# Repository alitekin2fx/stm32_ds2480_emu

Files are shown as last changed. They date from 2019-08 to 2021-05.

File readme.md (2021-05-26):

# STM32 DS2480 emulation project.
DS2480 is a 1-Wire line driver IC that works with OneWireLinkLayer library and several evaluation kit softwares from Maxim. In this project i have demostrated how to emulate DS2480 chip on STM32. You can use this usb stick to access your 1-Wire IC's with above softwares or with your own software using the OneWireLinkLayer library.

# How to upload firmware
1) Download and install the DfuSe application from ST.
2) Solder "DFU" jumper and plug it into USB port.
3) Install driver if needed.
4) Run DfuSe and press "choose" button under "Update and verify action" section.
5) Locate to *.dfu file (software/stm32_ds2480_emu.dfu)
5) Press "Upgrade" button
6) Press "Leave DFU mode" button.
8) Remove solder from "DFU" jumper

# Licenses
- Software license: MIT
- Hardware license: CERN v1.2

OSHW-TR000001 (https://certification.oshwa.org/tr000001.html)

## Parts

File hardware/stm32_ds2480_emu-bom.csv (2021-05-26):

Quantity | References | Value | Footprint | Brand | Part Number | LCSC Part #
2 | C1, C2 | 100nF | Capacitor_SMD:C_0603_1608Metric | SAMSUNG | CL10B104KB8NNNC
1 | C3 | 2.2uF | Capacitor_SMD:C_0603_1608Metric | SAMSUNG | CL10A225KO8NNNC
1 | C4 | 1uF | Capacitor_SMD:C_0603_1608Metric | SAMSUNG | CL10A105KO8NNNC
1 | D1 | LED1 | LED_SMD:LED_0603_1608Metric | LITEON | LTST-C190KGKT
1 | D2 | LED2 | LED_SMD:LED_0603_1608Metric | LITEON | LTST-C191KRKT
1 | D3 | 5.1V | Diode_SMD:D_SOT-23_ANK | HOTTECH | BZX84C5V1-HT
1 | F1 | Polyfuse | Fuse:Fuse_0805_2012Metric | BOURNS | MF-PSMF010X-2
1 | J2 | USB_A | Connector_USB:USB_A_CNCTech_1001-011-01101_Horizontal | CONNFLY | DS1098-WN0
1 | Q1 | SI2302CDS | Package_TO_SOT_SMD:SOT-23 | Vishay | SI2302CDS-T1-GE3
2 | R1, R2 | 100R | Resistor_SMD:R_0603_1608Metric | ROYALOHM | 0603SAJ0101T5E
1 | R3 | 2.2K | Resistor_SMD:R_0805_2012Metric | ROYALOHM | 0805S8J0222T5E
2 | R4, R7 | 4.7R | Resistor_SMD:R_0805_2012Metric | ROYALOHM | 0805S8J047JT5E
2 | R5, R6 | 10K | Resistor_SMD:R_0603_1608Metric | ROYALOHM | 0603SAJ0103T5E
1 | U1 | USBLC6-2SC6 | Package_TO_SOT_SMD:SOT-23-6 | STM | USBLC6-2SC6
1 | U2 | STM32F042F6Px | Package_SO:TSSOP-20_4.4x6.5mm_P0.65mm | STM | STM32F042F6P6
1 | U3 | AP2204K-3.3 | Package_TO_SOT_SMD:SOT-23-5 | DIODES | AP2204K-3.3TRG1

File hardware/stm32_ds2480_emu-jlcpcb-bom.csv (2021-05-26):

Comment | Designator | Footprint | LCSC Part #
100nF | C1,C2 | Capacitor_SMD:C_0603_1608Metric
2.2uF | C3 | Capacitor_SMD:C_0603_1608Metric
1uF | C4 | Capacitor_SMD:C_0603_1608Metric
LED1 | D1 | LED_SMD:LED_0603_1608Metric
LED2 | D2 | LED_SMD:LED_0603_1608Metric
5.1V | D3 | Diode_SMD:D_SOT-23_ANK
Polyfuse | F1 | Fuse:Fuse_0805_2012Metric
Fiducial | FID1,FID2 | Fiducial:Fiducial_0.5mm_Mask1.5mm
OW | J1 | Connector_PinHeader_2.54mm:PinHeader_1x02_P2.54mm_Vertical
USB_A | J2 | Connector_USB:USB_A_CNCTech_1001-011-01101_Horizontal
SWD | J3 | Connector_PinHeader_1.27mm:PinHeader_1x05_P1.27mm_Vertical
PUP | JP1 | Jumper:SolderJumper-2_P1.3mm_Open_RoundedPad1.0x1.5mm
DFU | JP2 | Jumper:SolderJumper-2_P1.3mm_Open_RoundedPad1.0x1.5mm
SI2302CDS | Q1 | Package_TO_SOT_SMD:SOT-23
100R | R1,R2 | Resistor_SMD:R_0603_1608Metric
2.2K | R3 | Resistor_SMD:R_0805_2012Metric
4.7R | R4,R7 | Resistor_SMD:R_0805_2012Metric
10K | R5,R6 | Resistor_SMD:R_0603_1608Metric
SYNC | TP1 | TestPoint:TestPoint_Pad_D1.0mm
NRST | TP2 | TestPoint:TestPoint_Pad_D1.0mm
USBLC6-2SC6 | U1 | Package_TO_SOT_SMD:SOT-23-6
STM32F042F6Px | U2 | Package_SO:TSSOP-20_4.4x6.5mm_P0.65mm
AP2204K-3.3 | U3 | Package_TO_SOT_SMD:SOT-23-5

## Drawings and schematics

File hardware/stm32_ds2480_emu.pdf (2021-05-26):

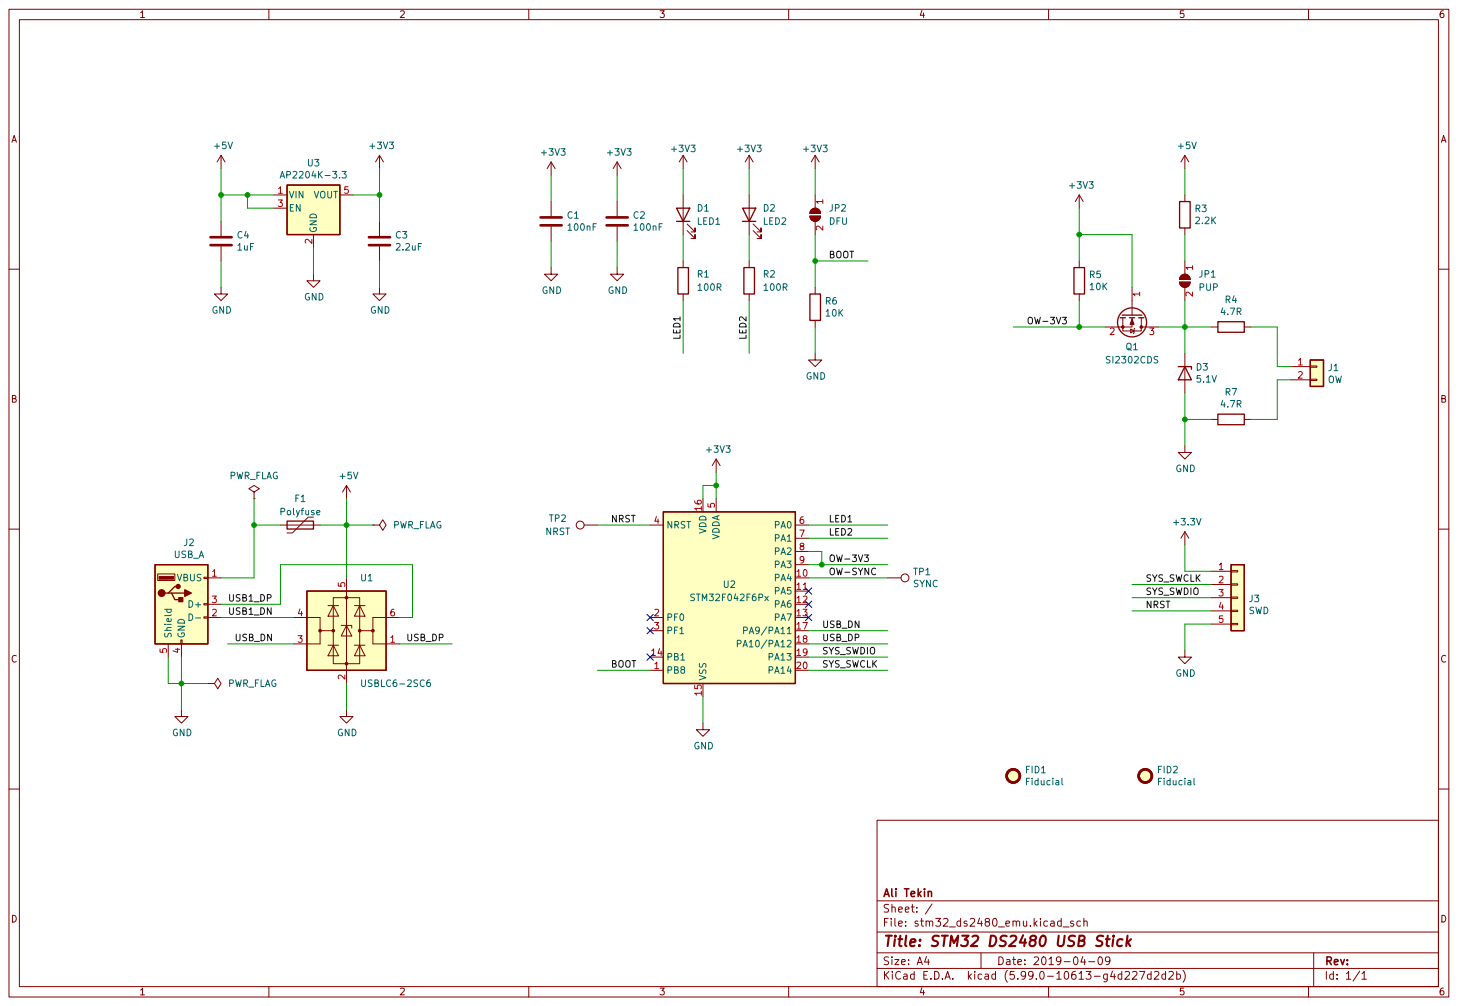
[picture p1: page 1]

File: stm32_ds2480_emu.kicad_sch Sheet: / Ali Tekin

Id: 1/1 Title: STM32 DS2480 USB Stick

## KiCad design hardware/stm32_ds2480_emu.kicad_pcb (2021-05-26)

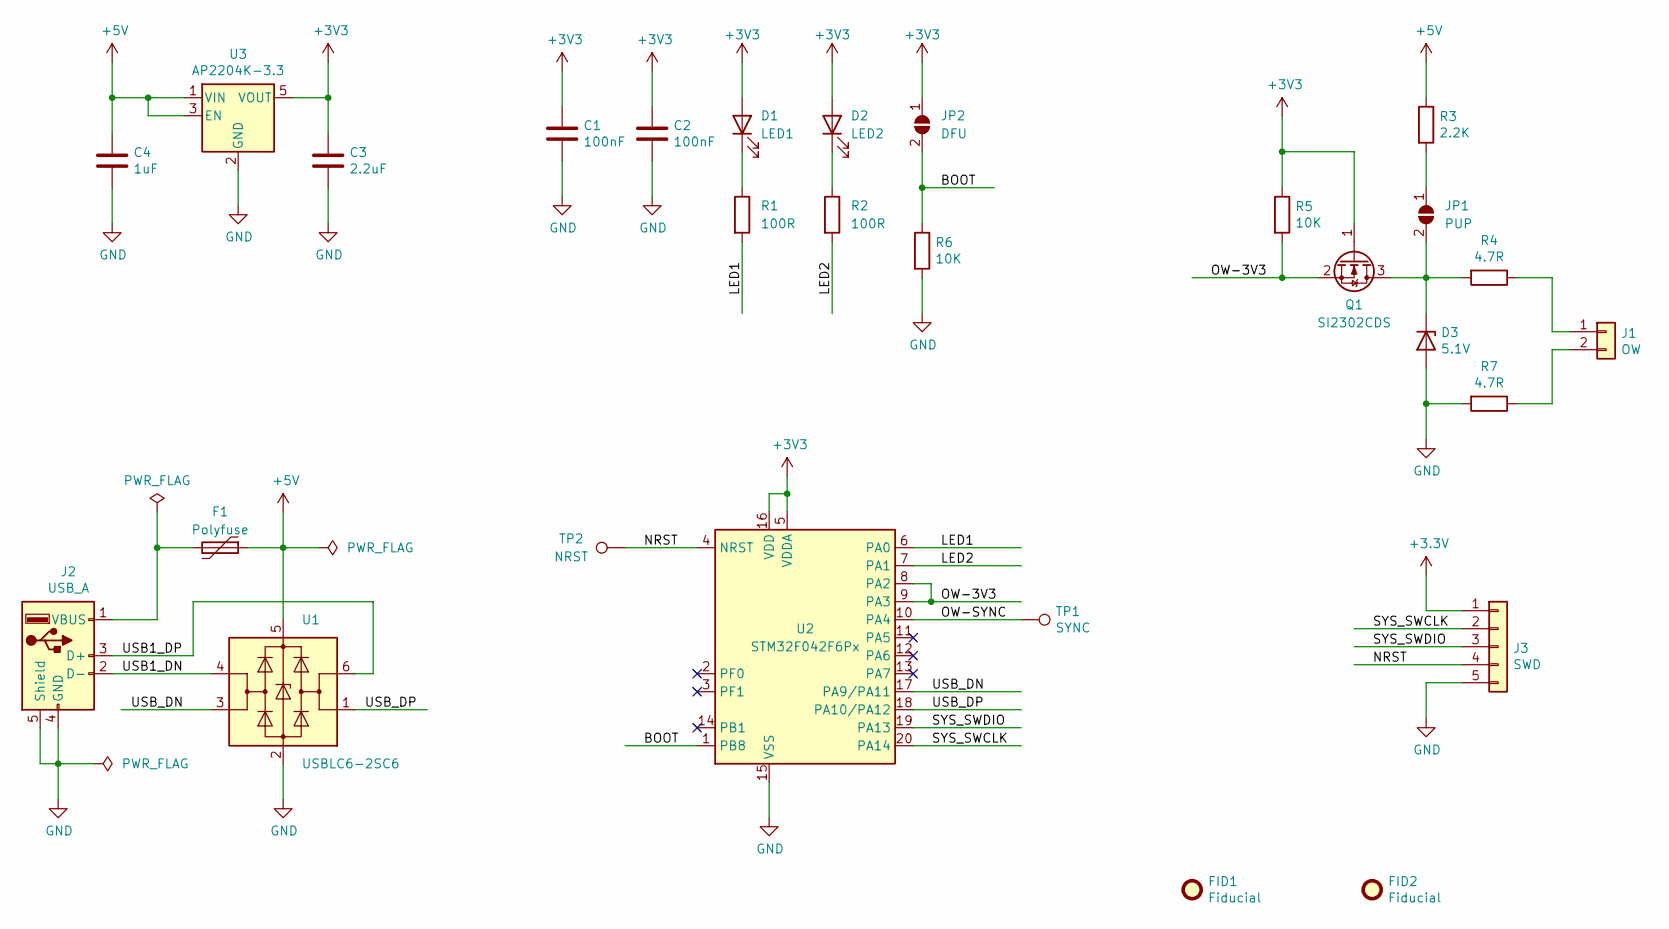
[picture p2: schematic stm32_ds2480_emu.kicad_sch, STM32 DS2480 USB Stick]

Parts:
C1, C2: 100nF; C_0603_1608Metric; Part Number CL10B104KB8NNNC
C3: 2.2uF; C_0603_1608Metric; Part Number CL10A225KO8NNNC
C4: 1uF; C_0603_1608Metric; Part Number CL10A105KO8NNNC
D1: LED1; LED_0603_1608Metric; Part Number LTST-C190KGKT
D2: LED2; LED_0603_1608Metric; Part Number LTST-C191KRKT
D3: 5.1V; D_SOT-23_ANK; Part Number BZX84C5V1-HT
F1: Polyfuse; Fuse_0805_2012Metric; Part Number MF-PSMF010X-2
FID1, FID2: Fiducial; Fiducial_0.5mm_Mask1.5mm
J1: OW; PinHeader_1x02_P2.54mm_Vertical
J2: USB_A; USB_A_CNCTech_1001-011-01101_Horizontal; Part Number DS1098-WN0
J3: SWD; PinHeader_1x05_P1.27mm_Vertical
JP1: PUP; SolderJumper-2_P1.3mm_Open_RoundedPad1.0x1.5mm
JP2: DFU; SolderJumper-2_P1.3mm_Open_RoundedPad1.0x1.5mm
Q1: SI2302CDS; SOT-23; Part Number SI2302CDS-T1-GE3
R1, R2: 100R; R_0603_1608Metric; Part Number 0603SAJ0101T5E
R3: 2.2K; R_0805_2012Metric; Part Number 0805S8J0222T5E
R4, R7: 4.7R; R_0805_2012Metric; Part Number 0805S8J047JT5E
R5, R6: 10K; R_0603_1608Metric; Part Number 0603SAJ0103T5E
TP1: SYNC; TestPoint_Pad_D1.0mm
TP2: NRST; TestPoint_Pad_D1.0mm
U1: USBLC6-2SC6; SOT-23-6; Part Number USBLC6-2SC6
U2: STM32F042F6Px; TSSOP-20_4.4x6.5mm_P0.65mm; Part Number STM32F042F6P6
U3: AP2204K-3.3; SOT-23-5; Part Number AP2204K-3.3TRG1

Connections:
+5V: C4.1, F1.1, R3.1, U1.5 (VBUS), U3.1 (VIN), U3.3 (EN)
/BOOT: JP2.2 (B), R6.1, U2.1 (PB8)
/LED1: R1.2, U2.6 (PA0)
/LED2: R2.2, U2.7 (PA1)
/NRST: J3.4, TP2.1, U2.4 (NRST)
/OW-3V3: Q1.2 (S), R5.2, U2.8 (PA2), U2.9 (PA3)
/OW-SYNC: TP1.1, U2.10 (PA4)
/SYS_SWCLK: J3.2, U2.20 (PA14)
/SYS_SWDIO: J3.3, U2.19 (PA13)
/USB1_DN: J2.2 (D-), U1.4 (I/O2)
/USB1_DP: J2.3 (D+), U1.6 (I/O1)
/USB_DN: U1.3 (I/O2), U2.17 (PA9/PA11)
/USB_DP: U1.1 (I/O1), U2.18 (PA10/PA12)
GND: C1.2, C2.2, C3.2, C4.2, D3.2 (A), J2.4 (GND), J2.5 (Shield), J3.5, R6.2, R7.2, U1.2 (GND), U2.15 (VSS), U3.2 (GND)
unnamed: D1.1 (K), R1.1
unnamed: D2.1 (K), R2.1
unnamed: D3.1 (K), JP1.2 (B), Q1.3 (D), R4.2
unnamed: F1.2, J2.1 (VBUS)
unnamed: J1.1, R4.1
unnamed: J1.2, R7.1
unnamed: JP1.1 (A), R3.2

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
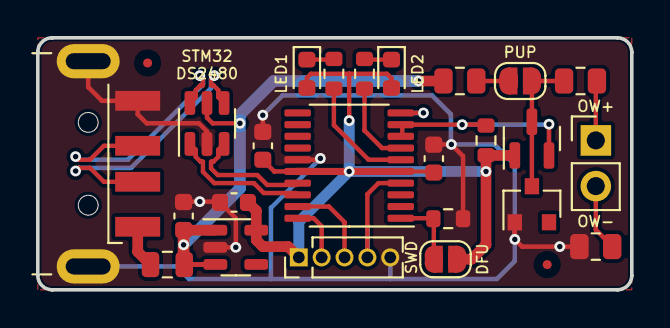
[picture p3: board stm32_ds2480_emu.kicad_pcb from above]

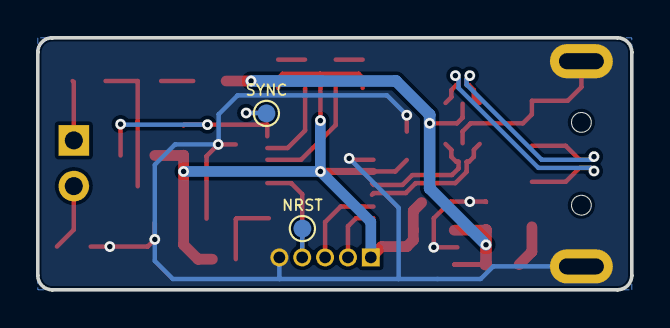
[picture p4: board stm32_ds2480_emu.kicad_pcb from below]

Board: 2 copper layers, 33.0 x 14.0 mm, 28 parts (2 on the bottom side), 22 nets.

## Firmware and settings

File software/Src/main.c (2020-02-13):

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

/* Includes ------------------------------------------------------------------*/
#include "main.h"
#include "usb_device.h"

/* USER CODE BEGIN Includes */
#include "ds2480b.h"
#include "usbd_cdc.h"

/* USER CODE END Includes */

UART_HandleTypeDef huart2;
DMA_HandleTypeDef hdma_usart2_rx;
DMA_HandleTypeDef hdma_usart2_tx;

/* USER CODE BEGIN PV */
struct ds2480b ds2480b;
uint32_t led1_tick_count;
uint32_t led2_tick_count;
__IO int cdc_receiver_busy;
__IO uint32_t cdc_rx_data_length;
__IO const uint8_t *cdc_rx_buffer;
extern USBD_HandleTypeDef hUsbDeviceFS;

/* USER CODE END PV */

void SystemClock_Config(void);
static void MX_GPIO_Init(void);
static void MX_DMA_Init(void);
static void MX_USART2_UART_Init(void);
/* USER CODE BEGIN PFP */

/* USER CODE END PFP */

/**
  * @brief  The application entry point.
  * @retval int
  */
int main(void)
{
  

  /* MCU Configuration--------------------------------------------------------*/

  /* Reset of all peripherals, Initializes the Flash interface and the Systick. */
  HAL_Init();

  /* USER CODE BEGIN Init */
  cdc_receiver_busy = 0;
  cdc_rx_data_length = 0;
  ds2480b_reset(&ds2480b);

  /* USER CODE END Init */

  /* Configure the system clock */
  SystemClock_Config();

  /* Initialize all configured peripherals */
  MX_GPIO_Init();
  MX_DMA_Init();
  MX_USART2_UART_Init();
  MX_USB_DEVICE_Init();
  /* Infinite loop */
  /* USER CODE BEGIN WHILE */
  while (1)
  {
	  if (!cdc_receiver_busy)
	  {
		  if (cdc_rx_data_length != 0)
		  {
			  ds2480b_handle_data(&ds2480b, (const uint8_t*)cdc_rx_buffer, cdc_rx_data_length);
			  cdc_rx_data_length = 0;
		  }

		  if (hUsbDeviceFS.pClassData != 0)
		  {
			  cdc_receiver_busy = 1;
			  USBD_CDC_ReceivePacket(&hUsbDeviceFS);
		  }
	  }

	  if (HAL_GPIO_ReadPin(LED1_GPIO_Port, LED1_Pin) == GPIO_PIN_RESET)
	  {
		  if (HAL_GetTick() - led1_tick_count > 100)
			  HAL_GPIO_WritePin(LED1_GPIO_Port, LED1_Pin, GPIO_PIN_SET);
	  }

	  if (HAL_GPIO_ReadPin(LED2_GPIO_Port, LED2_Pin) == GPIO_PIN_RESET)
	  {
		  if (HAL_GetTick() - led2_tick_count > 100)
			  HAL_GPIO_WritePin(LED2_GPIO_Port, LED2_Pin, GPIO_PIN_SET);
	  }
    /* USER CODE END WHILE */

    /* USER CODE BEGIN 3 */

  }
  /* USER CODE END 3 */
}

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
/* USER CODE BEGIN 4 */
void cdc_break_callback()
{
	ds2480b_reset(&ds2480b);
}

void cdc_data_received_callback(const uint8_t *data, uint32_t data_length)
{
	cdc_rx_buffer = data;
	cdc_rx_data_length = data_length;
	cdc_receiver_busy = 0;
}

/* USER CODE END 4 */
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


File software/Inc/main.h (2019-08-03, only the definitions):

#define LED1_Pin GPIO_PIN_0
#define LED1_GPIO_Port GPIOA
#define LED2_Pin GPIO_PIN_1
#define LED2_GPIO_Port GPIOA
#define OW_TX_Pin GPIO_PIN_2
#define OW_TX_GPIO_Port GPIOA
#define OW_RX_Pin GPIO_PIN_3
#define OW_RX_GPIO_Port GPIOA
#define OW_SYNC_Pin GPIO_PIN_4
#define OW_SYNC_GPIO_Port GPIOA

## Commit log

2019-05-12 Firmware added
    [stm32_ds2480_emu Debug.cfg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]
2019-05-30 Uart changed to one bit sample mode
2019-08-03 Upgraded to CubeMx 5.2.1
    [stm32_ds2480_emu Debug.cfg]
2019-08-31 All componenets moved to top side
    [stm32_ds2480_emu-B_Cu.gbr, stm32_ds2480_emu-B_Fab.gbr, stm32_ds2480_emu-B_Mask.gbr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]
2019-09-12 DMA receive error fixed
    [owuart.c]
2020-02-07 New USB stick PCB design
    [stm32_ds2480_emu-B_Cu.gbr, stm32_ds2480_emu-B_Fab.gbr, stm32_ds2480_emu-B_Mask.gbr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]
2020-02-13 A potential bug is fixed
    [main.c]
2021-05-26 Started using KiKit for the panelization.
    [stm32_ds2480_emu-bom.csv, stm32_ds2480_emu-jlcpcb-bom.csv, stm32_ds2480_emu.csv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]
2021-08-26 Error interrupts are disabled because of incomplete data transfer
    [owuart.c]

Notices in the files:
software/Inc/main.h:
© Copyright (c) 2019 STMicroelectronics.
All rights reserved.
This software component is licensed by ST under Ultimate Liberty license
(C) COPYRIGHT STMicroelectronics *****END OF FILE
